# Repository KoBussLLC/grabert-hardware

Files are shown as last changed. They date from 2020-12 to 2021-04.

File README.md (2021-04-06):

# Grabert Keyboard Hardware

💻 🖥️ ⌨️ Open-source ~60% Mechanical Keyboard 🎉

Build Guide and additional information [here](doc/BUILDGUIDE.md)!

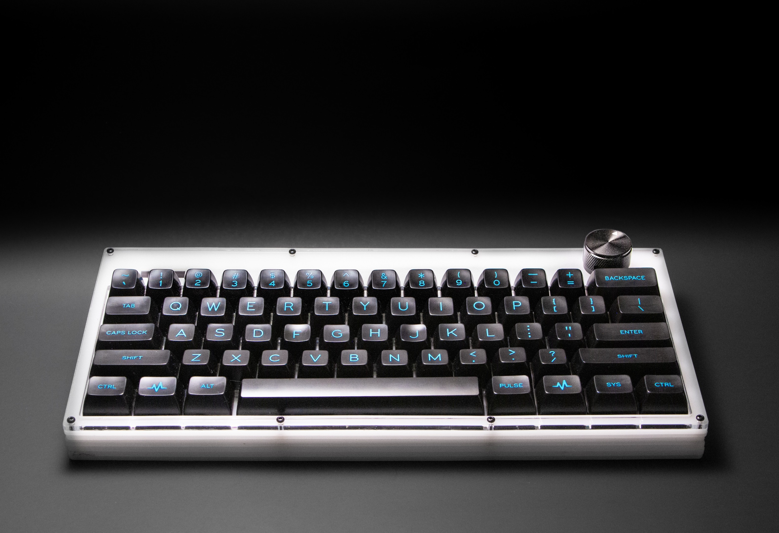
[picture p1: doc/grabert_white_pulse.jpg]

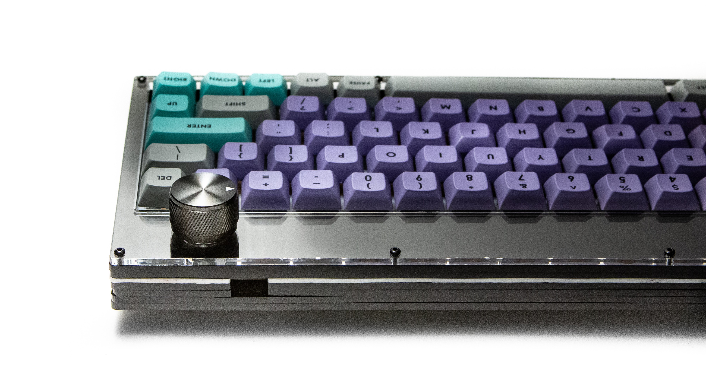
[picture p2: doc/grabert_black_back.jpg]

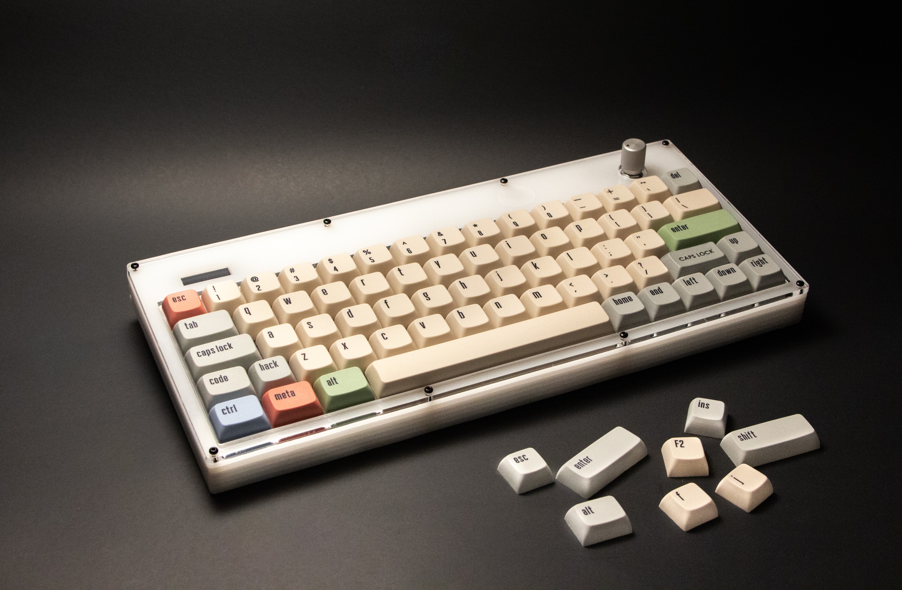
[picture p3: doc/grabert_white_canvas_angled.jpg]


<details>
  <summary>Screen and Foot</summary>
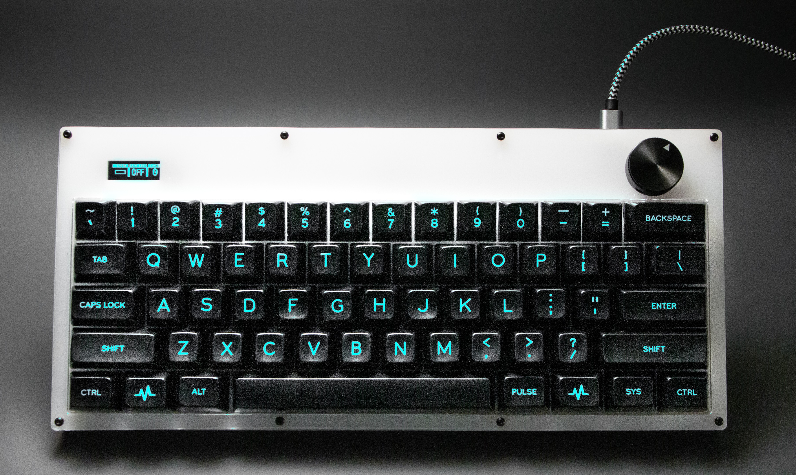
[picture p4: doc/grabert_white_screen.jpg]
  
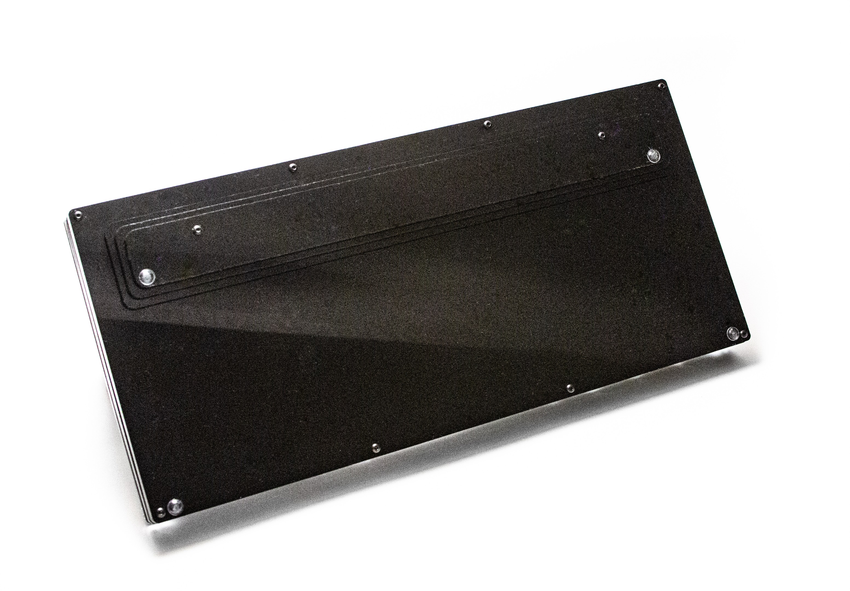
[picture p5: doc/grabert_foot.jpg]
  
</details>
<br/>
<details>
  <summary>PCB Images</summary>
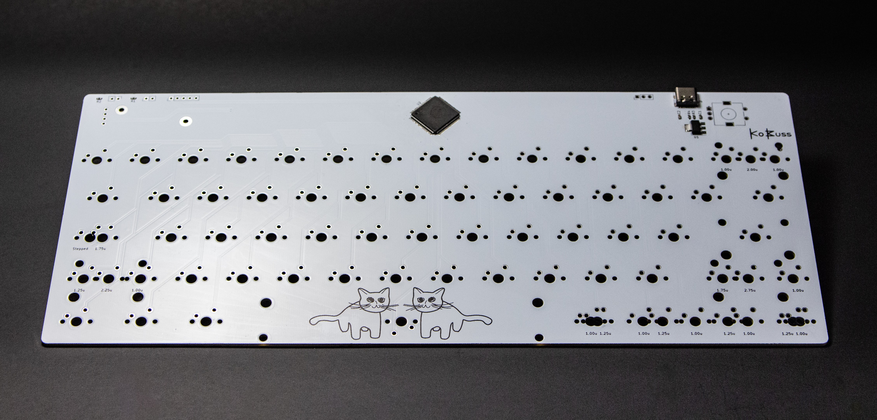
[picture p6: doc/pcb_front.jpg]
  
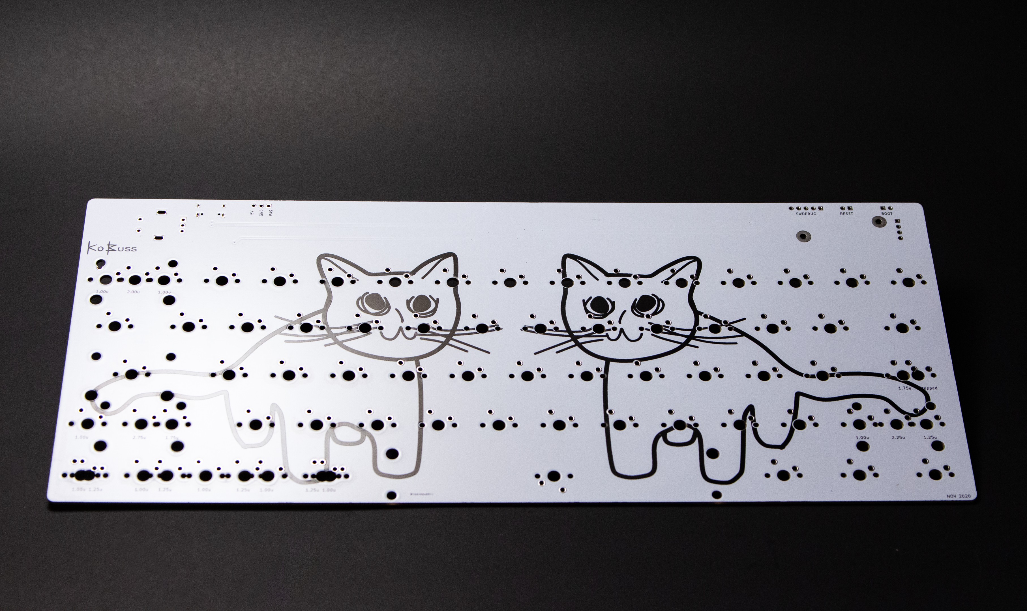
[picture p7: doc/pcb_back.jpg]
  
</details>
<br/>

[PCB design video](https://youtu.be/ezk02GJ9iMs)

[Case design video](https://youtu.be/DsW-hKeB3mc)

## Features

- OLED Screen
- Rotary Knob
- Sandwich Mount Case
- POM Switch Plate
- [4 Layout Options](doc/BUILDGUIDE.md#preparation-and-layout-decision)
- 32-bit Microcontroller

### Powered by

- [QMK](https://github.com/qmk/qmk_firmware) ([KoBuss QMK Fork](https://github.com/KoBussLLC/qmk_firmware))
- [VIA](https://caniusevia.com/)

## PCB

This project uses KiCad 6 for electrical CAD

### Electrical Design Constraints
- No diode matrix enabled by LQFP 100 MCU Footprint
- 32-bit STM32 Microcontroller (STM32F072V8T6)
- USB-C
- PCB Mount Switches
- PCB Mount Stabilizers
- Push-Button Encoder
- 0.91" 128x32px I2C OLED Display (SSD1306)

### Changes
- V0 had incorrectly valued bypass capacitors. Testing showed no obvious issues, but it is not preferable.

## CAD

This project uses FreeCAD 0.19 for mechanical CAD

### Required Add-ons
- Assembly 4
- Fasteners
- kicadStepUpMod

### Mechanical Design Contraints
- ~60% Keyboard Layout
- 5 Layout Options
- Push Button Encoder
- OLED 128x32 Screen
- Fully Laser Cut Case
- POM Switch Plate
- 2mm diameter fasteners

### Acrylic Sheet Stackup

Main Case Stackup. "0" is the bottom of the case.

| Sheet Number | FreeCAD "Part" | Thickness | Material | Shape |
| - | - | - | - | - |
| 0 | bottom | 0.125 in | Acrylic |  |
| 1 | closed_spacer | 0.125 in | Acrylic |  |
| 2 | usb_spacer | 0.125 in | Acrylic |  *with feet |
| 3 | usb_spacer | 0.125 in | Acrylic |  *with feet |
| 4 | switch_plate | 0.0625 in | POM/Acetal |  |
| 5 | closed_spacer | 0.125 in | Acrylic |  |
| 6 | colored_top | 0.125 in | Acrylic |  |
| 7 | clear_top | 0.125 in | Acrylic |  |

#### Angled Foot Stackup

Foot stackup. "0" is closest to the case and is on the "top"

| Sheet Number | FreeCAD "Part" | Thickness | Material |
| - | - | - | - |
| 0 | foot_0 | 0.125 in | Acrylic |
| 1 | foot_1 | 0.125 in | Acrylic |
| 2 | foot_2 | 0.125 in | Acrylic |

## License
MIT License

Copyright (c) 2021 KoBuss LLC

Permission is hereby granted, free of charge, to any person obtaining a copy of this hardware, software, and associated documentation files (the "Product"), to deal in the Product without restriction, including without limitation the rights to use, copy, modify, merge, publish, distribute, sublicense, and/or sell copies of the Product, and to permit persons to whom the Product is furnished to do so, subject to the following conditions:

The above copyright notice and this permission notice shall be included in all copies or substantial portions of the Product.

THE PRODUCT IS PROVIDED "AS IS", WITHOUT WARRANTY OF ANY KIND, EXPRESS OR IMPLIED, INCLUDING BUT NOT LIMITED TO THE WARRANTIES OF MERCHANTABILITY, FITNESS FOR A PARTICULAR PURPOSE AND NONINFRINGEMENT. IN NO EVENT SHALL THE AUTHORS OR COPYRIGHT HOLDERS BE LIABLE FOR ANY CLAIM, DAMAGES OR OTHER LIABILITY, WHETHER IN AN ACTION OF CONTRACT, TORT OR OTHERWISE, ARISING FROM, OUT OF OR IN CONNECTION WITH THE PRODUCT OR THE USE OR OTHER DEALINGS IN THE PRODUCT.

### For the Keyboard Community
You can produce and sell this keyboard. KoBuss LLC is not liable. Creator attribution is preferred but not required.

### License Change?
We initially licensed this under the Creative Commons Attribution-NonCommercial 4.0 International License, but have since decided to change it to MIT.
This would not be appropriate if the product was in production and had been forked/derived, but because we made the license change early on we deemed it acceptable.
If you have any issues with this change, please contact us directly.

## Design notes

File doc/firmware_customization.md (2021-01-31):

# Firmware Customization

## QMK Firmware

The keyboard firmware shipped with all Grabert keyboard is QMK with VIA enabled. To see the latest firmware, see the [KoBuss QMK Fork](https://github.com/KoBussLLC/qmk_firmware). It is reccomended to use VIA for keyboard configuration before diving into firmware customization, but it is only natural to see what mischief you can accomplish with your own 1's and 0's 💾.

The current firmware uses the OLED screen for WPM speed, caps lock indicator, and layer indicator. The images are hard coded using the `grabert.h` file and the [image2cpp](https://javl.github.io/image2cpp/) website is used to convert pixels into vertically packed bits. If you want to change what gets displayed, remove all the OLED logic and implement your own, or simply use image2cpp in the vertical mode to create the arrays your code needs 🎨.

By default the bottom-right modifiers and right shift are toggle-tap keys that are arrow keys on "tap" and modifiers on "hold", but you can use other advanced features by changing the keymap and possibly the config and make file.

### DFU and Reset

The STM32F072 series has an internal USB bootloader that is booted into from a software reset or by a hardware reset. It is much easier to use the software reset. To use the software reset, get into layer 2 with right and left modifiers and press the rotary encoder. If you change the keymap so that you can not trigger a software reset, you must take the case apart and trigger the reset in hardware. The boot pin must be pulled high while the MCU is reset. To do this on the Grabert PCB, simply use a wire and connect the boot jumper and while the boot jumper is connected, connect the reset jumper and the release the jumper. See the image in the *Debugger Programming* section for reference.

You should see a STMicroelectronics device show up your device tree, which means that your PCB is ready to be programmed.  `STMicroelectronics STM Device in DFU Mode`

To program your new firmware, flash a compiled bin with `dfu-util`. The STM32F072V8 only containes 64 Kbytes of flash, so make sure to not go crazy with too many stored images for the OLED. To learn more about building the firmware see the QMK docs.

Build Command
``` sh
make kobuss/grabert:via
```

Build and Flash Command
``` sh
make kobuss/grabert:via:dfu-util
```
### Debugger Programming

**This is not normally needed unless you need breakpoints or register level access**

To fully debug your firmware, you will need a JTAG or ST-Link programming device. Connect it to the SWD pins on the PCB and start a debug sesion!

To access the SWD pins, you must take the case apart:
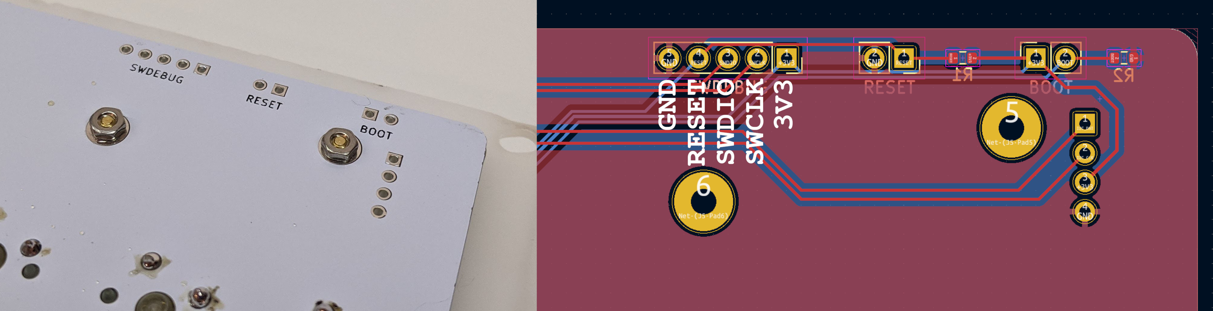
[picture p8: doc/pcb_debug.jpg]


### Extending Functionality

#### LED Underlighting
Pin A9 of the STM32072 is broken out on the left of the USB, along with the USB 5V rail and ground. Pin A9 is a TIM1_CH2 enabled pin and therefore could be used for dimmable single color underglow or bit banged for an RGB string. This is not officially supported but may be documented further in the future.

This pin could also be used as an input in a case where you want a giant mechanical switch for some special function.

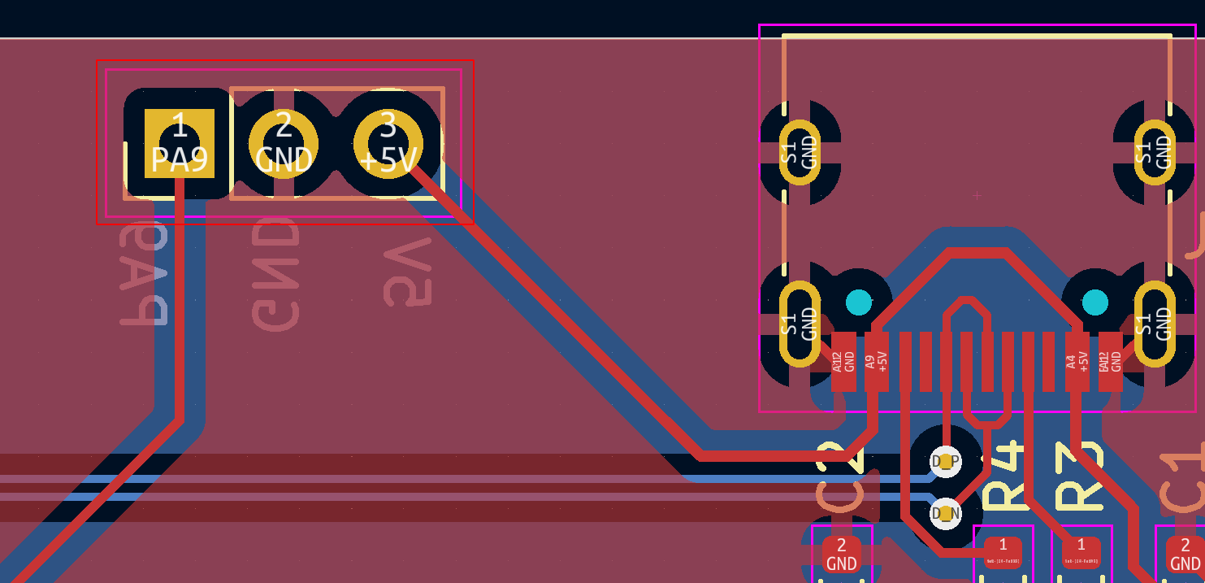
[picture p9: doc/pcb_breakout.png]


### Wanted QMK additions to Grabert
If you are working on the firmware for Grabert and want to see what you might be able to add, the following is a list of things that we believe others could benefit from.

- Implement STM32 RTC to enable programable clock to display on the OLED
- Add configurable WS2812 or PWM based LED on PA9
- Crazy cool OLED implementations!
- Add custom VIA "eeprom" storage for encoder along with custom VIA implementation of the encoder

## Rust Firmware

TODO: Fork an existing Rust keyboard firmware and write a Grabert implementation

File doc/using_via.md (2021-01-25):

# Using VIA

QMK firmware with VIA enabled is the default firmware on all Grabert keyboards. VIA allows for dynamic changing of keymaps through a desktop application. VIA does not currently support all of the advanced [software features of QMK](https://docs.qmk.fm/#/feature_auto_shift), so if you are interested in using those, see the [firmware customization documentation](firmware_customization.md).

For all official VIA documentation see the VIA [website](https://caniusevia.com/) and QMK's  [repository]().

## Setting up VIA for Grabert

1. Download VIA from the [official website](https://caniusevia.com/) for your respective OS.

2. As of right now, Grabert is not in the upstream VIA keyboards repo, therefore you also need to download the [grabert.json](https://raw.githubusercontent.com/KoBussLLC/keyboards/kobuss/src/kobuss/grabert/grabert.json) from the KoBussLLC fork. (Click the hyperlink and right-click "Save Page As..." into your computer)
   
3. Launch VIA through your OS
4. Select "Import Keymap" from your OS's menu
5. Select the `grabert.json` file from your computer that you just downloaded
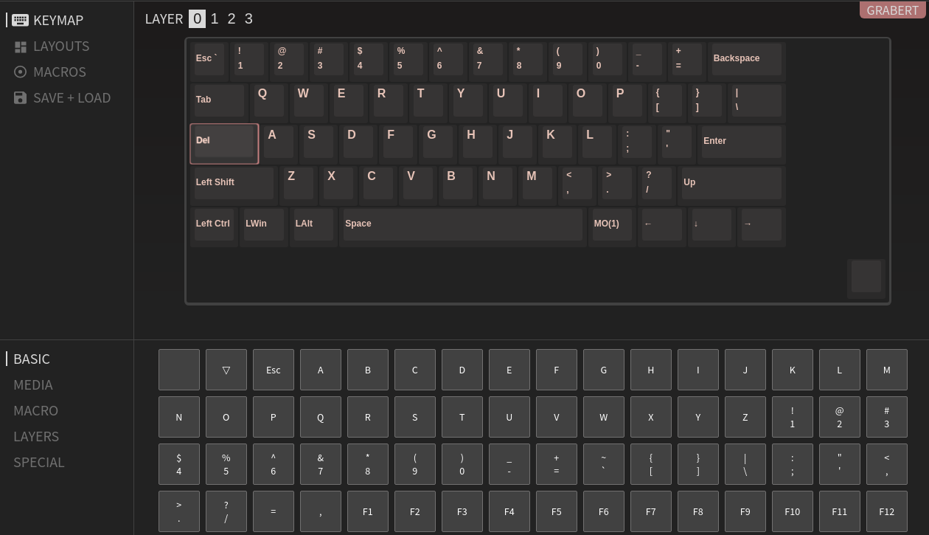
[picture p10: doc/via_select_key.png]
6. Use VIA in whatever way you want. The main operations are selecting a layer and then a key and choosing what you want the coresponding key to represent. Note that the mapping changes immediately after selecting a new key for the highlighted switch. 
7. Dive into setting up custom "Macros" and advanced layering once you are ready.

### Additional Information

- [Keyboard Layout Editor Permalink](http://www.keyboard-layout-editor.com/##@@_x:3%3B&=0,0&=0,1&=0,2&=0,3&=0,4&=0,5&=0,6&=0,7&=0,8&=0,9&=0,10&=0,11&=0,12&_w:2%3B&=0,13%0A%0A%0A0,0&_x:0.5%3B&=0,13%0A%0A%0A0,1&=0,14%0A%0A%0A0,1%3B&@_x:3&w:1.5%3B&=1,0&=1,1&=1,2&=1,3&=1,4&=1,5&=1,6&=1,7&=1,8&=1,9&=1,10&=1,11&=1,12&_w:1.5%3B&=1,13%3B&@_x:3&w:1.75%3B&=2,0&=2,1&=2,2&=2,3&=2,4&=2,5&=2,6&=2,7&=2,8&=2,9&=2,10&=2,11&_w:2.25%3B&=2,12%3B&@_w:1.25%3B&=3,0%0A%0A%0A1,1&=3,1%0A%0A%0A1,1&_x:0.75&w:2.25%3B&=3,0%0A%0A%0A1,0&=3,2&=3,3&=3,4&=3,5&=3,6&=3,7&=3,8&=3,9&=3,10&=3,11&_w:2.75%3B&=3,12%0A%0A%0A2,0&_x:0.5&w:1.75%3B&=3,12%0A%0A%0A2,1&=3,13%0A%0A%0A2,1%3B&@_x:3&c=%23AAAAAA&w:1.25%3B&=4,0&_w:1.25%3B&=4,1&_w:1.25%3B&=4,2&_c=%23cccccc&w:6.25%3B&=4,3&_c=%23AAAAAA&w:1.25%3B&=4,4%0A%0A%0A3,0&_w:1.25%3B&=4,5%0A%0A%0A3,0&_w:1.25%3B&=4,7%0A%0A%0A3,0&_w:1.25%3B&=4,8%0A%0A%0A3,0%3B&@_y:0.25&x:13%3B&=4,4%0A%0A%0A3,1&=4,5%0A%0A%0A3,1&=4,6%0A%0A%0A3,1&=4,7%0A%0A%0A3,1&=4,8%0A%0A%0A3,1&_x:1.5&c=%23cccccc%3B&=4,9) used to generate the VIA grabert.json file
- [VIA Layout documentation](https://caniusevia.com/docs/layouts)

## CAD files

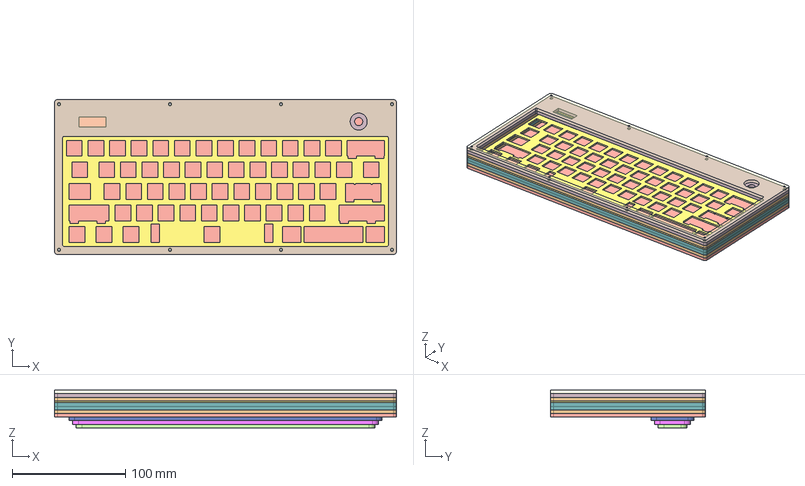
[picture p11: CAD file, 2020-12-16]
CAD/grabert.FCStd
301.6 x 136.5 x 33.3 mm

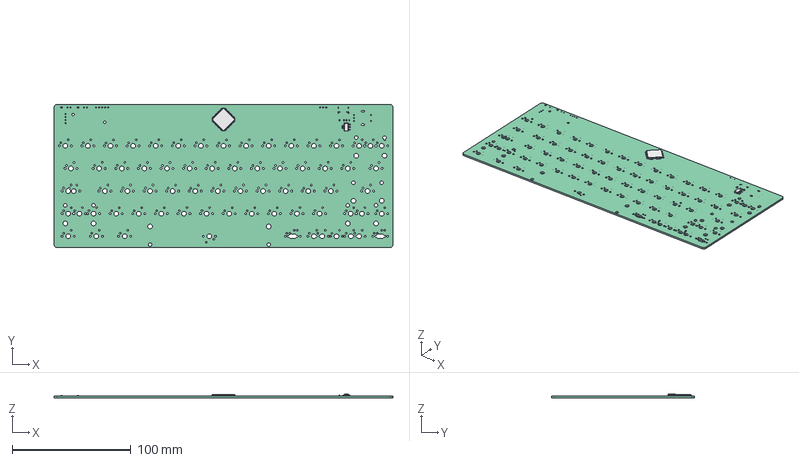
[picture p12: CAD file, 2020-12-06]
CAD/grabert_pcb.FCStd
285.8 x 120.7 x 3.30 mm
Pcb_4306
"C1"_C_0603_1608Metric_5db69710-2d0d-45d7-a742-beb49e07931f x 2
"U2"_LQFP_100_14x14mm_P05mm_719b990f-ae4c-490b-9cd7-5392cd54d5f2
"R2"_R_0603_1608Metric_b3f198d9-8440-4a91-92b4-b595c153e976 x 4
"U1"_SOT_223_c46af92f-9185-4327-9a7a-dfaa81b7fe2d

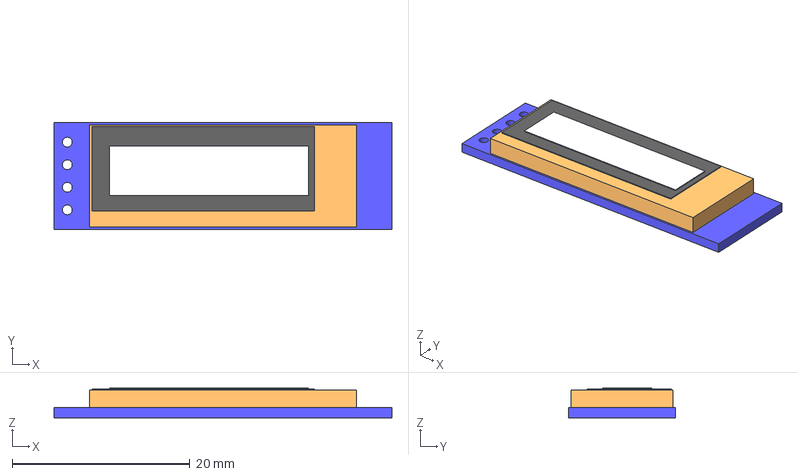
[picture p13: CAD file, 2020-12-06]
CAD/ssd1306oled128x32.FCStd
38.0 x 12.0 x 3.35 mm
Glass
PCB
BlackFilm
Pixel Area

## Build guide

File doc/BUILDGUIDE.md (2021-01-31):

# Grabert Build Guide
- [Grabert Build Guide](#grabert-build-guide)
  - [Preparation and Layout Decisions](#preparation-and-layout-decisions)
    - [Determining Your Layout](#determining-your-layout)
    - [Required Components that are not supplied](#required-components-that-are-not-supplied)
    - [Required Tools](#required-tools)
  - [Build Instructions](#build-instructions)
    - [PCB Testing and Setup](#pcb-testing-and-setup)
    - [Switch Plate Assembly](#switch-plate-assembly)
    - [Case Assembly](#case-assembly)
  - [Errata](#errata)
## Preparation and Layout Decisions
### Determining Your Layout
The first step in building your keyboard is deciding what layout you want to use. If you have already picked out a keycap set, make
sure that the layout you choose can be achieved with the keycaps that you have.
With a standard 60% layout, Grabert uses 61 PCB Mount MX style switches with 1x 6.25U and 4x 2.00U PCB mount stabilizers. Grabert can be built with both PCB mount and plate mount MX switches, while the PCB mount switches provide better alignment but more difficult installation, and the plate mount switches are the inverse.  Grabert offers 4 layout options that can change these component requirements, as shown in the table below. With that said, it is recommended to have at least 3 extra switches on hand in case you have a wild child spring or you just have a mysterious defunct switch.

| Option | Key Size Change | Switch Requirement Change | Stabilizer Requirement Change |
|-|-|-|-|
| Split Backspace | 2.0U ⇨ 1.0U + 1.0U  | +1 | -1x 2.00U |
| Split Left Shift | 2.25U ⇨ 1.25U + 1.0U | +1 | -1x 2.00U |
| Split Right Shift | 2.75U ⇨ 1.75U + 1.0U | +1 | -1x 2.00U |
| Five Right Modifiers | 5x 1.25U ⇨ 4x 1.0U | +1 | No Change |

If this is your first time building a keyboard, it may be nice to use a default 60% layout, as you will still be able to use the right modifiers (bottom-right hand corner) as tapped arrow keys and any keycap set supports this layout. Use KLE's preset as an [example](http://www.keyboard-layout-editor.com/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'&_w:2.25%3B&=Enter%3B&@_w:2.25%3B&=Shift&=Z&=X&=C&=V&=B&=N&=M&=%3C%0A,&=%3E%0A.&=%3F%0A%2F%2F&_w:2.75%3B&=Shift%3B&@_w:1.25%3B&=Ctrl&_w:1.25%3B&=Win&_w:1.25%3B&=Alt&_a:7&w:6.25%3B&=&_a:4&w:1.25%3B&=Alt&_w:1.25%3B&=Win&_w:1.25%3B&=Menu&_w:1.25%3B&=Ctrl). Grabert supports a "1.25U" stem stepped caps lock key.

Grabert default layout:

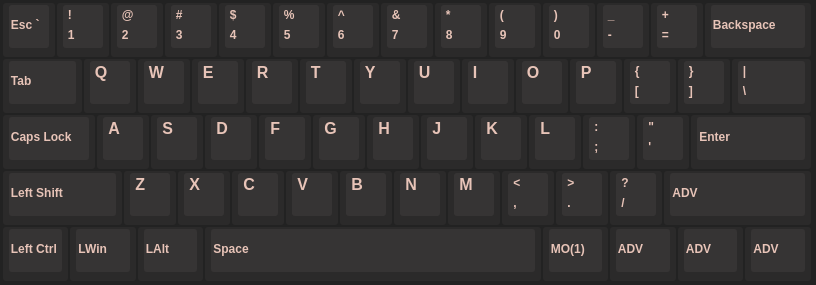
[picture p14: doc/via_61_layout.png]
Grabert 61 key layout


Grabert with all layout options utilized:

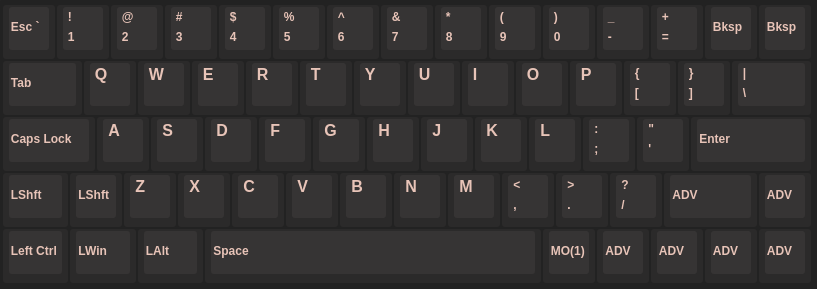
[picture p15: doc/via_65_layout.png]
Grabert 65 key layout


Once you have your layout chosen, grab your favorite switches and get them lubed!

We use [Super Lube 51004](https://www.amazon.com/gp/product/B000UKUHXK/) for our switches and [Super Lubes 21030](https://www.amazon.com/gp/product/B06WLQ251B/) for our stabilizers, but use whatever you like. We loosely follow [Taeha Types's Switch Lubing Guide](https://youtu.be/qSgPKPoFo2k) and [Taeha Types's Clipping, Lubing, and Band-aiding Guide](https://youtu.be/cD5Zj-ZgMLA) as a process for lubing our personal switches and stabilizers.

### Required Components that are not supplied

- Keycaps (Options: [Amazon](https://www.amazon.com/gp/product/B081DDG7CJ/), [MK](https://mechanicalkeyboards.com/shop/index.php?l=product_list&c=429&show=100&sortby=num_sold:desc))
- PCB Mount MX Style Switches (See [above](#determining-your-layout) for quantity) (Option: [Amazon](https://www.amazon.com/gp/product/B07TYD6Z3R/))
- PCB Mount Stabilizers (See [above](#determining-your-layout) for size/quantity) (Option: [Amazon](https://www.amazon.com/gp/product/B07ZLXCWY9/))
- Switch/Stabilizer Lubricant (**Optional**)
- USB-C Cable (Option: [Amazon](https://www.amazon.com/gp/product/B07VQYLXJC/))

### Required Tools

| Tool | Purpose |
|-|-|
| Soldering Iron and Solder | Soldering in MX style switches |
| Metric Hex Keys (1.5mm & 2mm) | Assembling the case |
| Small Phillips Head ScrewDriver| Screwing in PCB Mount Stabilizers |
| Pliers | Tightening hex nuts |
| Rubber Band | Holding the OLED Screen in place |
| Wire or Paperclip | Testing PCB Connections |

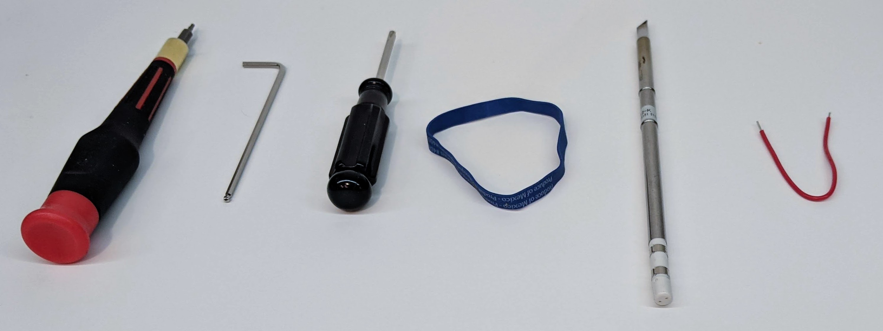
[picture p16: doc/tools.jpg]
Required Tools


## Build Instructions

The beginning of the build is the most difficult, so get your coffee or tea and get going! ☕🔨

### PCB Testing and Setup
1. Launch VIA and import the `grabert.json` keymap. If you do not know how to do this, see the [Using VIA guide](using_via.md).
2. Plug-in your Grabert PCB via the USB-C connector and make sure that VIA recognizes the keyboard. (Note: We test all PCBs are recognized before shipment, but this makes sure everything is working correctly when delivered.)
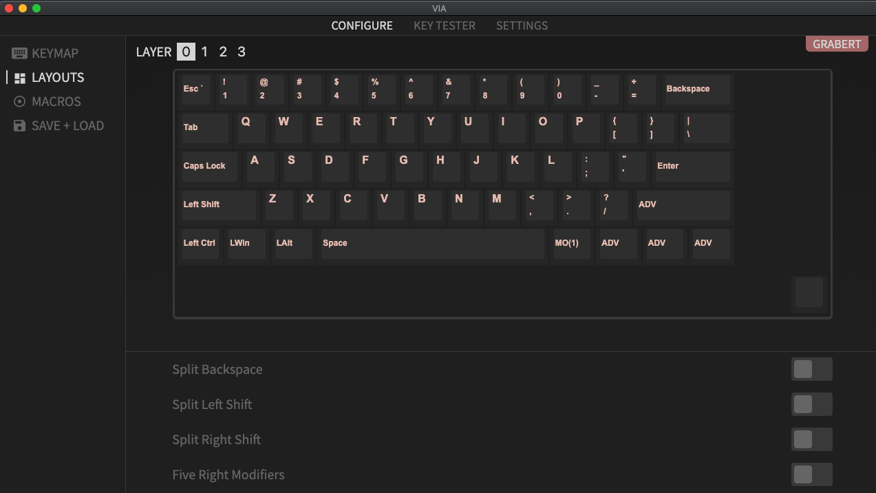
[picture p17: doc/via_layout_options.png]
3. Go to the "LAYOUTS" section and define which layout options you want. See the [Determining Your Layout](#determining-your-layout) section for help on determining what you should use. 
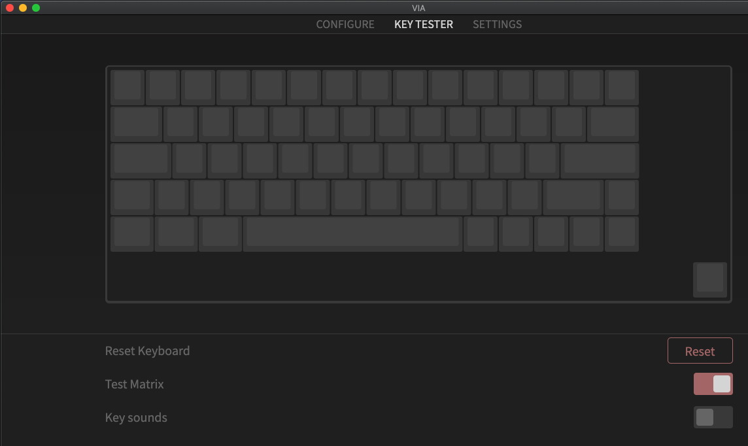
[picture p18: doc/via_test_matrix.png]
4. Go to the "KEY TESTER" panel in VIA and toggle the "Test Matrix" 
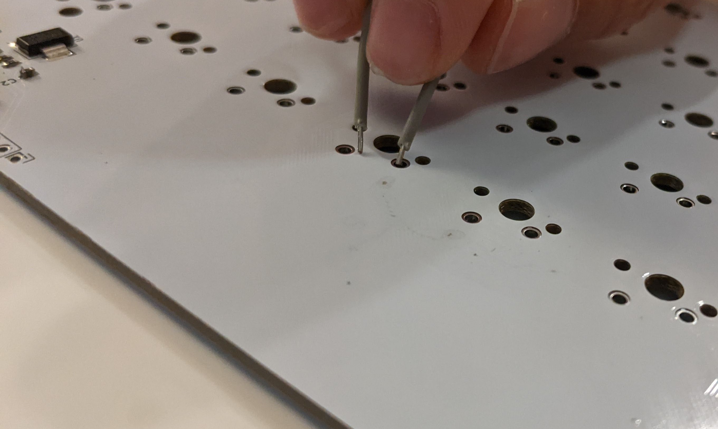
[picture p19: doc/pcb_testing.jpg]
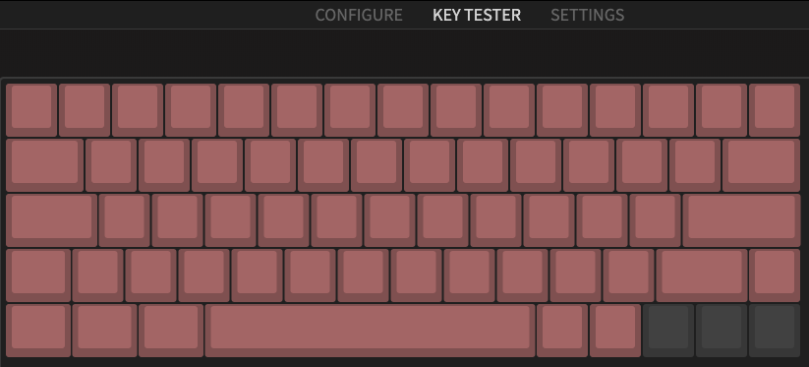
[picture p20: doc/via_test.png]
5. Use a spare wire or a paperclip to test that each key is registered. You do not need to light up the lone square at the bottom right corner, as this represents the encoder.  
6. Unplug the USB-C cable from the PCB once all keys are "lit" except for the bottom-right hand key. If not all keys light up, contact us at kobussllc@gmail.com
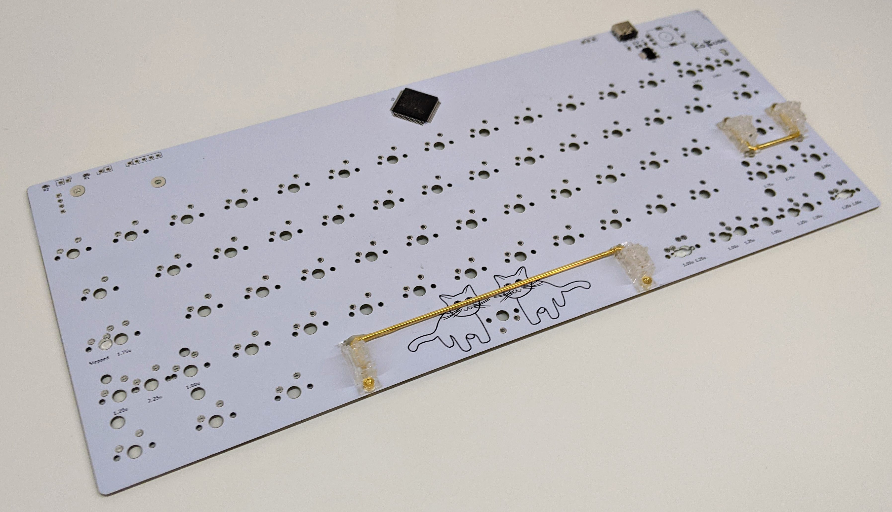
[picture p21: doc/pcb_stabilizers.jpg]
7. Lubricate your stabilizers if you wish, and then install them onto the PCB. To install the stabilizers, snap them onto the PCB and screw them in from the back of the PCB. The side of the stabilizer with the screw hole goes into the smaller hole in the PCB. The screw hole will be towards the top for all the small stabilizers and towards the bottom for the large space bar stabilizer (reference the picture). Screw them in slightly past hand tight. 

### Switch Plate Assembly

1. Gather the POM switchplate and your lubricated switches. Place **all** the switches that match your layout pattern that you have chosen into the switch plate. The metallic pins of the switches should be towards the top edge, except for the space bar. Feel free to reference the PCB, as the switch pins should fit into the holes.
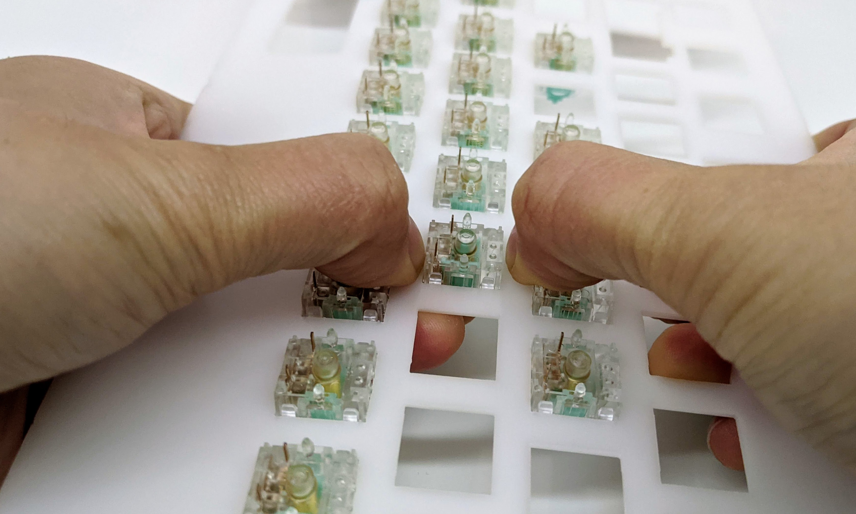
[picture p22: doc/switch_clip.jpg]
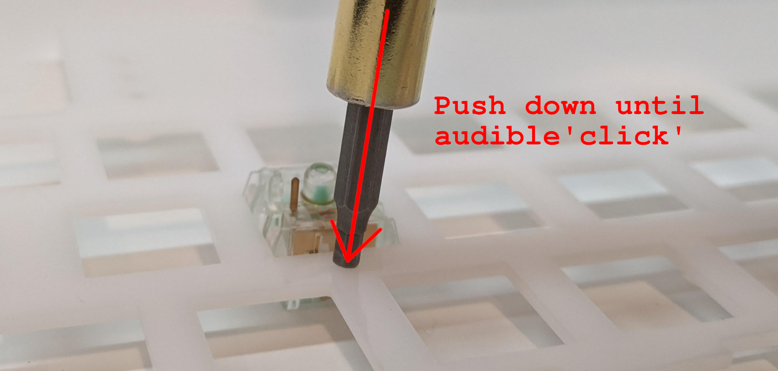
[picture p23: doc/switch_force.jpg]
To make sure that the switch is “clipped” in place and is securely in the switch plate, use your thumb and opposing finger to apply pressure at the clip in point and the switch plate. Make sure you hear a clicking sound (sometimes faint). This may be difficult on your hands, so you can use a blunt object like a screwdriver to apply direct pressure to the area of the switchplate next to the clip of the switch. (See [Errata](#errata) for why this is)  In spaces like the right modifier area, make sure you reference the PCB to make sure the switches are in the correct location of the cutout. Note: The switch should be perpendicular to the switchplate.  
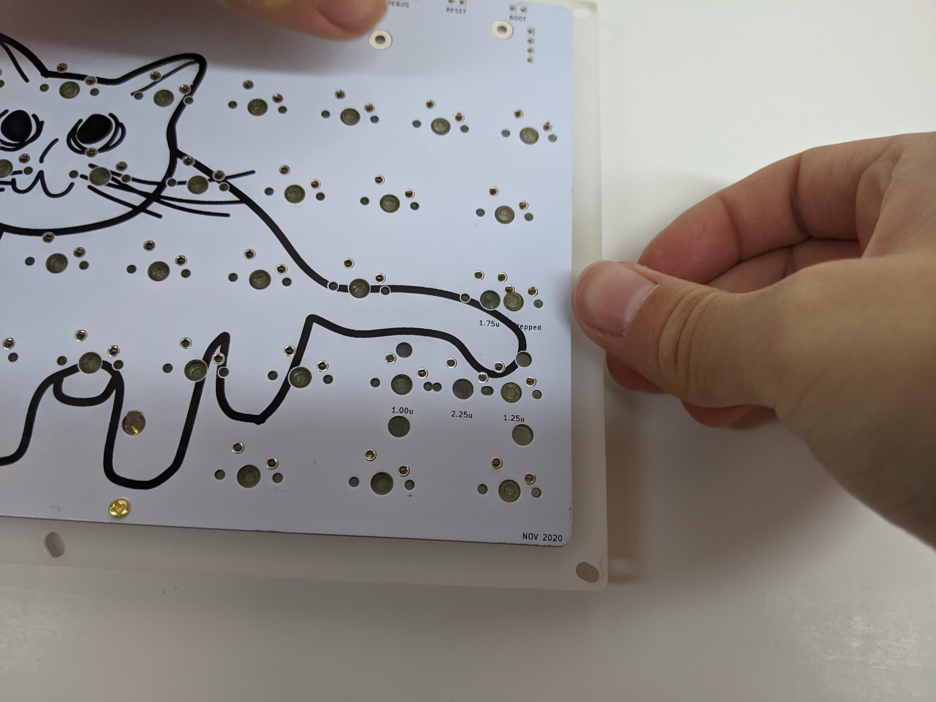
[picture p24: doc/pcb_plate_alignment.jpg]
2. With all of the switches in the switch-plate, place the switch plate onto the PCB. This step may seem simple, but it is important to do it without applying pressure that may push the switches out of the switch-plate or bend the pins. Make sure you can see all the pins aligned with the desired holes before applying any pressure.  You may also need to correct for any switch placement misalignment. 
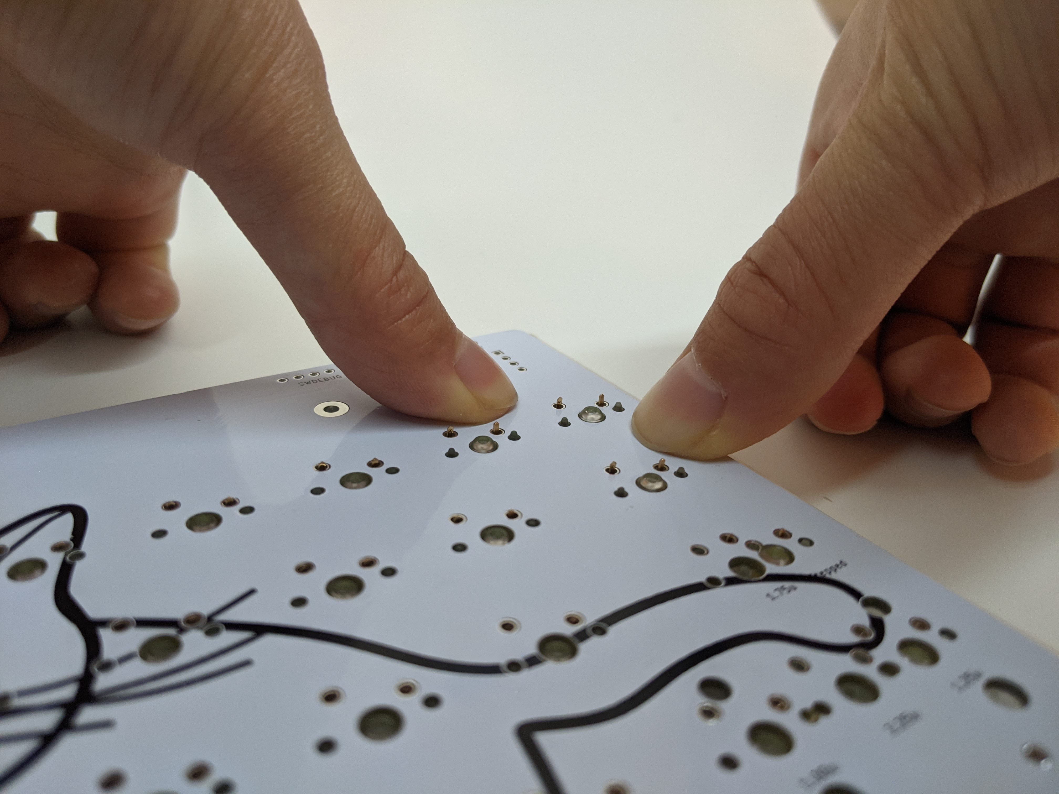
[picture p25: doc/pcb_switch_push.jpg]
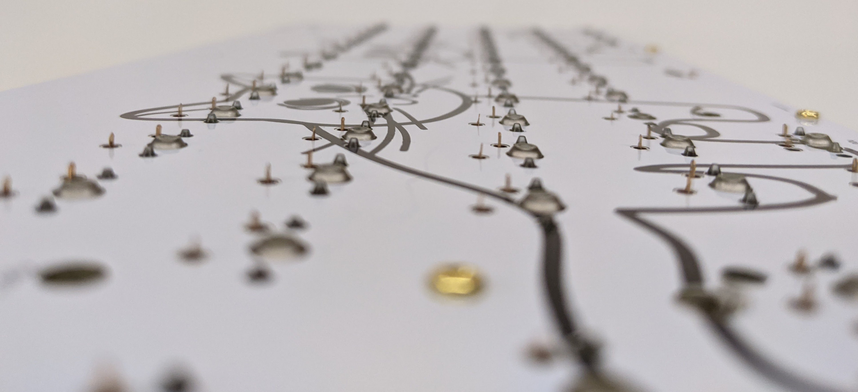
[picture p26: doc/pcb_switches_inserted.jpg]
3. Press down on the PCB, with the top of the switches touching your work surface. This may take quite a bit of pressure and is best done from one corner to another. Another method is to pick up the PCB and apply opposite pressure with single switches and the PCB. Make sure that all switches are pressed in all the way and perpendicular. Any misalignment here could cause your keycaps to touch each other.  
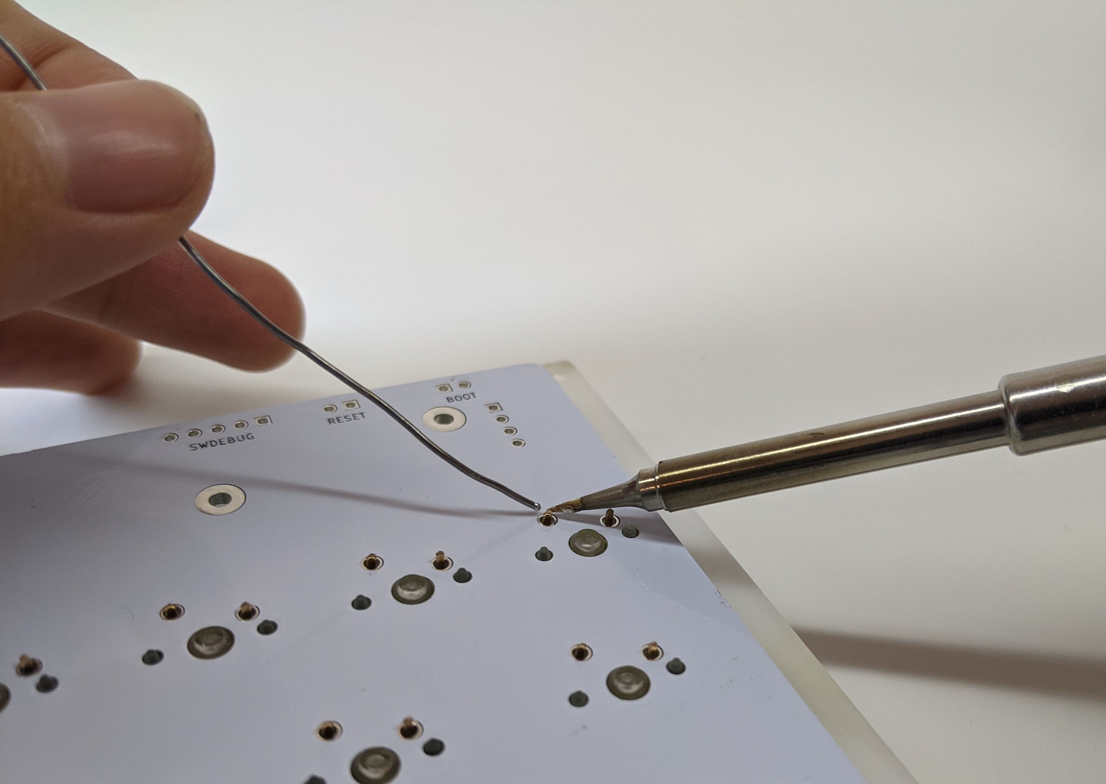
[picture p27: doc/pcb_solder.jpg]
4. With all the switches inserted into the PCB, with the switch plate sandwiched between, solder all pins of the switches. Note that the bottom pin is the ground pin and may take more heat from your soldering iron. [Sparkfun's Soldering Guide](https://learn.sparkfun.com/tutorials/how-to-solder-through-hole-soldering/all) for reference. 
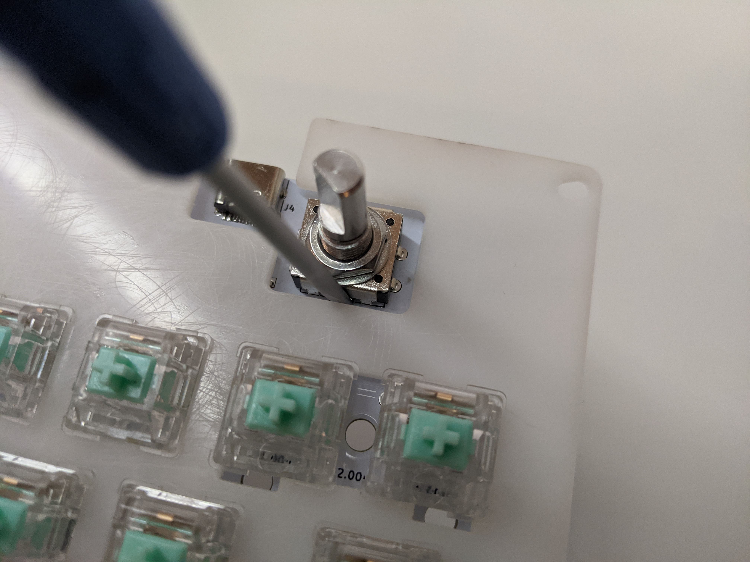
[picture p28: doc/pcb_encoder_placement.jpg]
5. After soldering all the switches, take the encoder and forcefully place the pins into the PCB's top-right corner. If it is feeling extra difficult, you may need to push on the tabs with a screwdriver to make the encoder snap into place. 
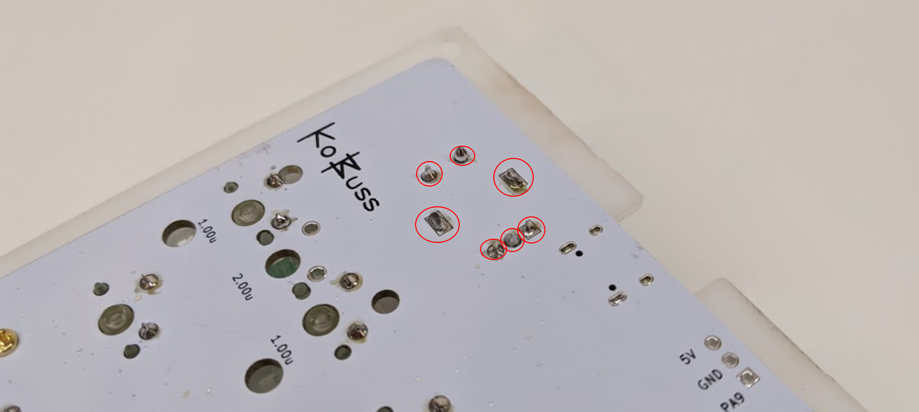
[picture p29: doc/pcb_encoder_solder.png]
6. Solder all 7 pins of the rotary encoder and make sure to take off the washer and nut on the top of the rotary encoder. 
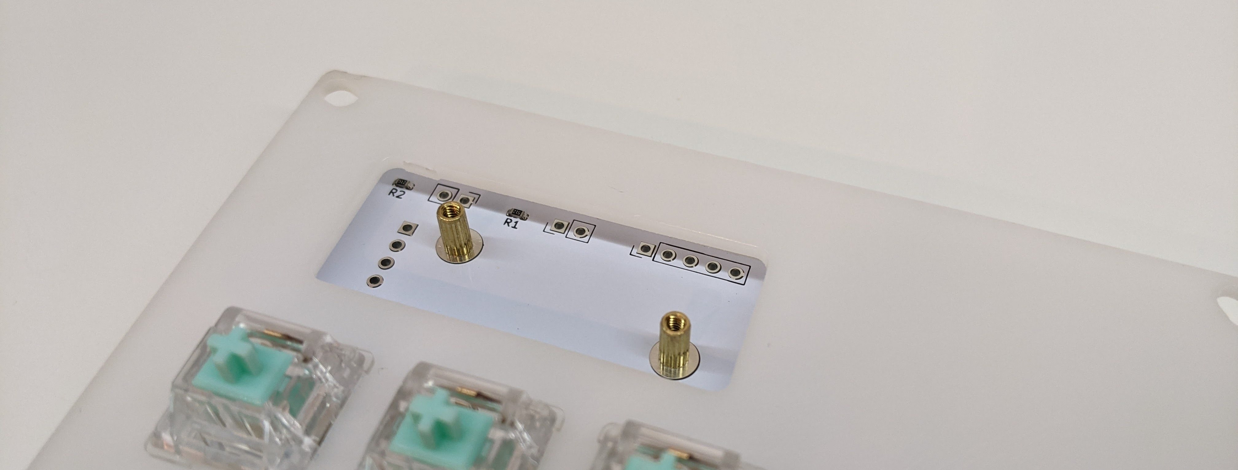
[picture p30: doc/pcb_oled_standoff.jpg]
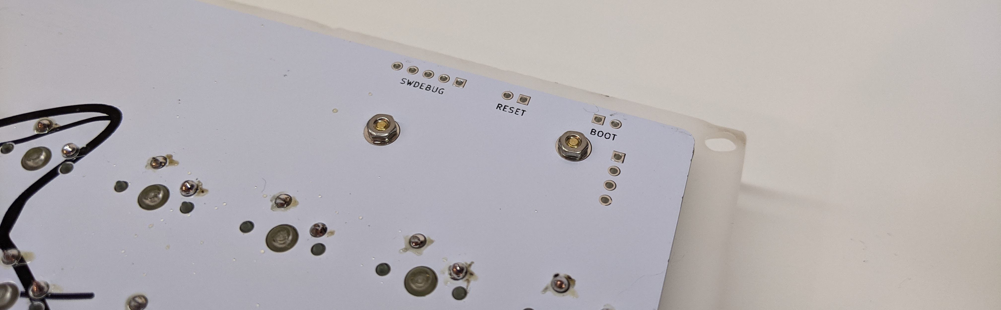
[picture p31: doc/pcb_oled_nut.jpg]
7. Take the two 6mm standoffs with 2mm nuts and fasten them in the holes on the PCB under the OLED. These standoffs will support the OLED installation for easy alignment. The nuts can be tightened with pliers just past hand tight.  
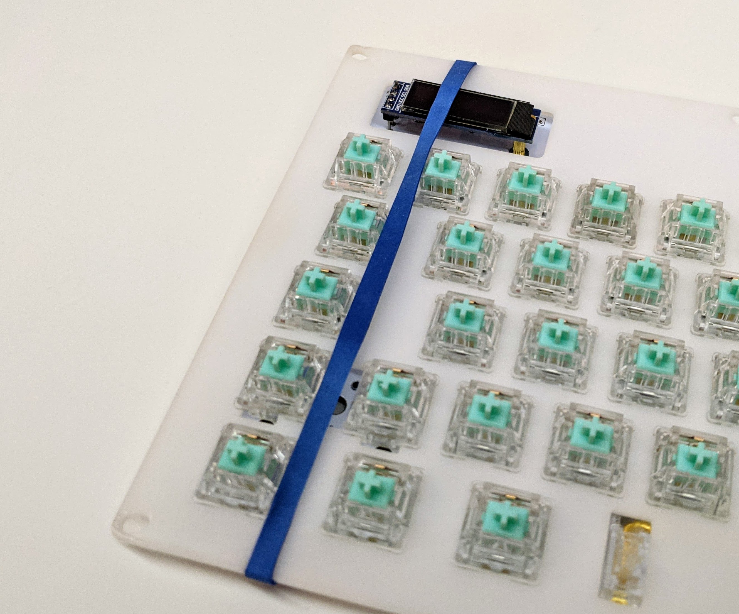
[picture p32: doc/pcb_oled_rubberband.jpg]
8. Insert the OLED display (peel the protective sheet off) into the top and rest it upon the installed standoffs. Recommended: Stretch a rubber band around the assembly to hold the OLED in place while you solder it. If you cannot get your OLED to be aligned both horizontally and vertically you may need to **gently** bend the pins that are connected to the OLED PCB. 
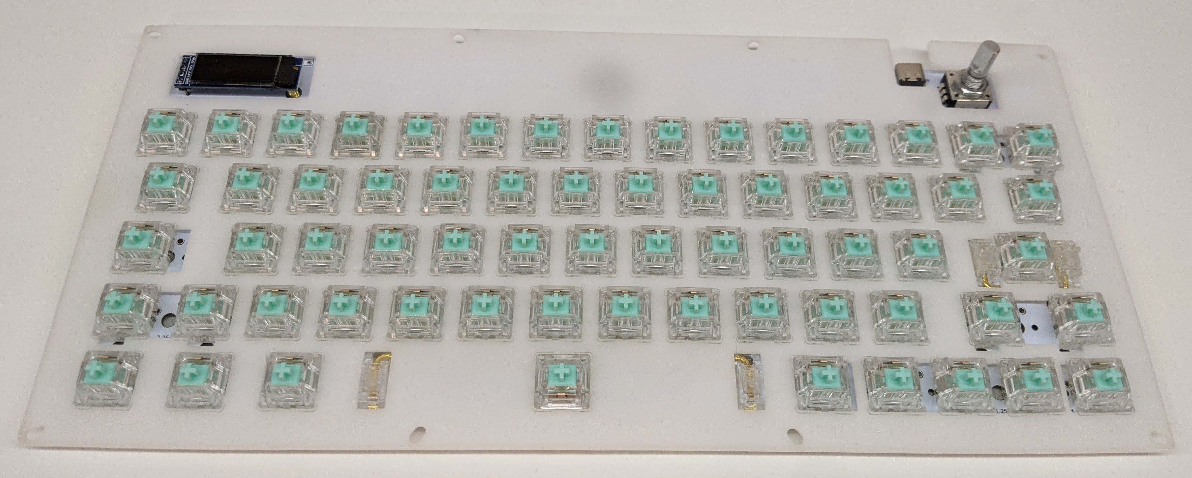
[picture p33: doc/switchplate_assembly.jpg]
9. Solder the four pins of the OLED display and make sure the display is aligned. It is alway good to solder just one pin and check alignment before soldering the rest of the pins. Note that the ground (bottom) pin may take some extra soldering heat. 
10. Plug the switch plate assembly into the your computer via the USB-C connector
11. Go back to the "KEY TESTER" in VIA and reset the keyboard. Press all the switches to test and see if your soldering was successful. If some of the switches don’t work, check your solder connections and pins. If the OLED does not work, check its connections as well.
12. Unplug your partially assembled keyboard, we are in the home stretch! 🏁🏃

### Case Assembly

1. Clean the OLED display and solder joints with a cloth coated in isopropyl alcohol. **Do not clean the acrylic case with isopropyl alcohol as it will cause the acrylic to crack!**
2. Grab the casing materials and start with the bottom plate along with two 6mm standoffs and four screws (Skip the standoffs and foot pieces if you do not want an inclined keyboard)
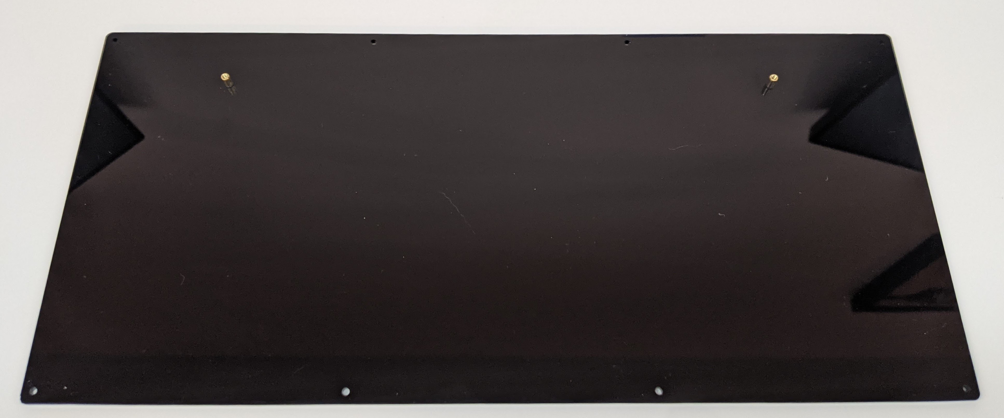
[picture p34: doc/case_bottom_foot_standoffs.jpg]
3. The bottom plate is symmetrical, so pick a side and call it "the top". Screw the two 6mm standoffs into the “center” holes with two screws. Hand tight is adequate. 
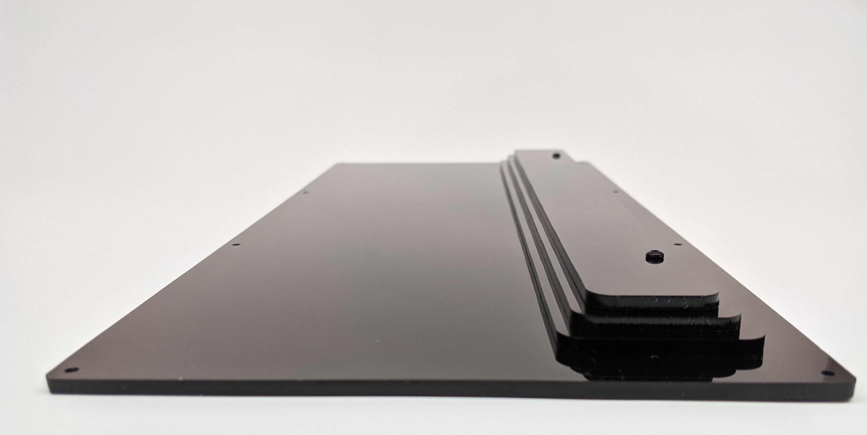
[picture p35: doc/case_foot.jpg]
4. Place the acrylic foot pieces from largest to smallest onto the standoffs. Capture the smallest acrylic piece by screwing in the remaining 2mm screws hand tight. The holes in the acrylic feet should be towards the top of the keyboard. 
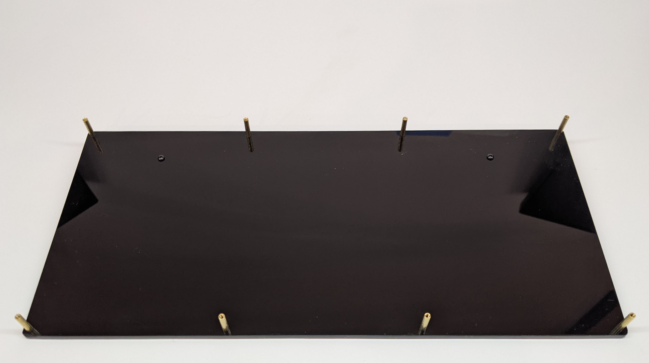
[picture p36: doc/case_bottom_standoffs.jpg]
5. Gather the rest of the standoffs (8) and 8 screws. Align a standoff with one of the holes on the top side of the base (opposite side of where the foot is) and screw in a screw to the standoff on the other side. Repeat 7 more times. 
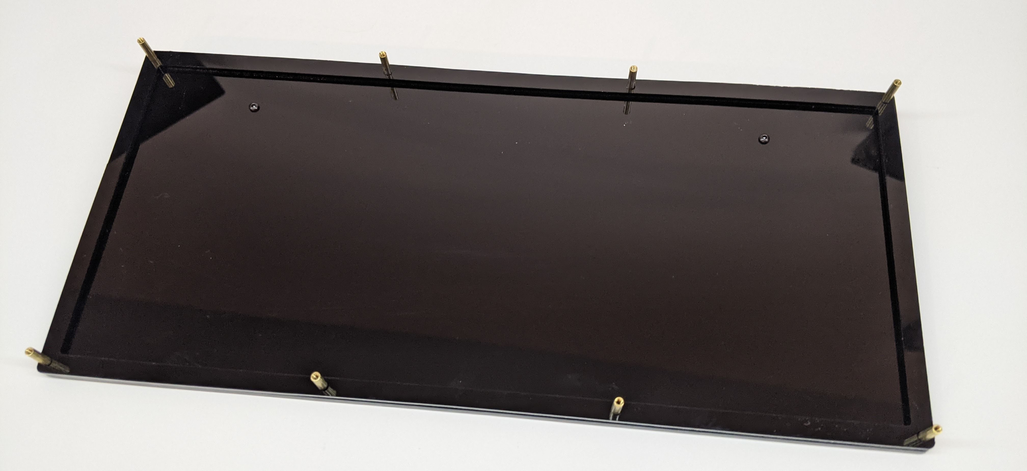
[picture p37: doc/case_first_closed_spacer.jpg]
6. Grab one closed spacer and press the spacer onto the base, aligning the holes of the spacer to the standoffs 
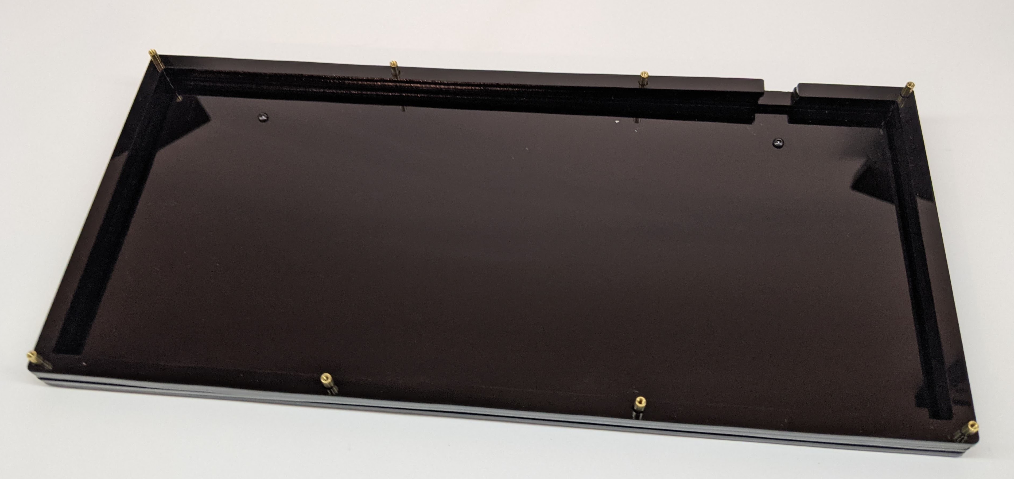
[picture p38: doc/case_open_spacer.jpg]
7. Place two open spacers on top, aligning the USB cut out to the right side. 
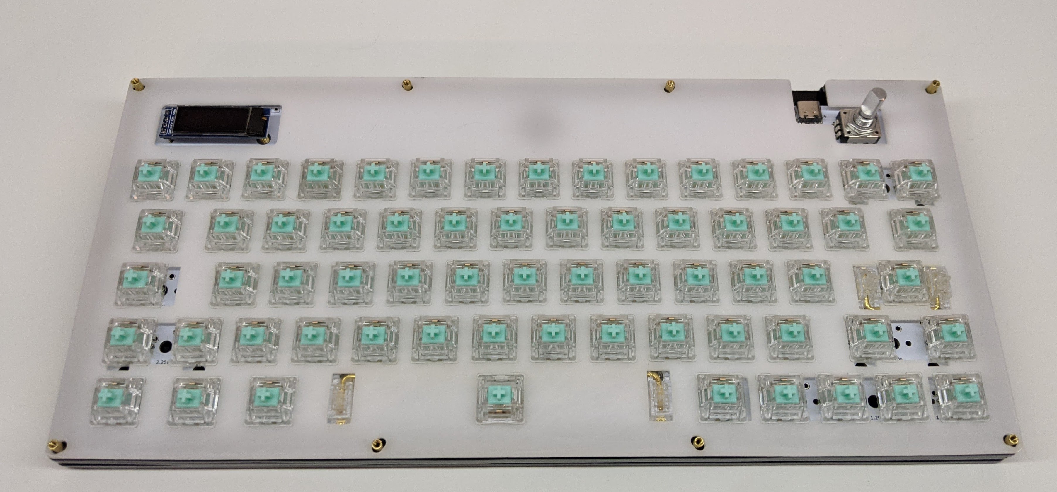
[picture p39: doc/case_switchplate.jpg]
8. Place your completed switch plate assembly on top.  
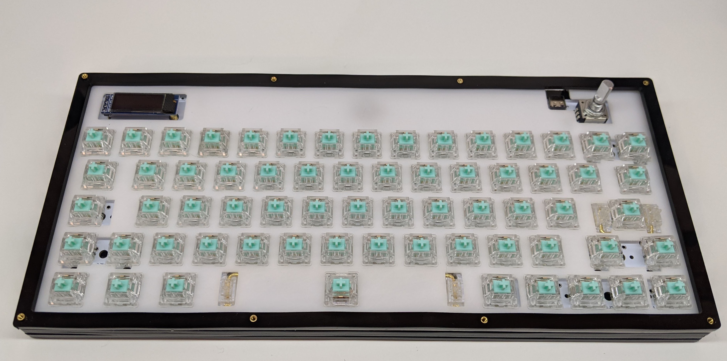
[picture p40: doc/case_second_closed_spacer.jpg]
9. Place the last closed spacer onto the switchplate. 
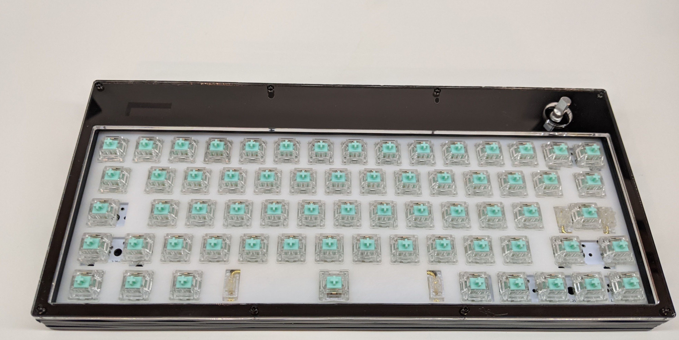
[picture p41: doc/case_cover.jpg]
10. Lastly, grab the opaque top with the opening for the OLED screen and align the holes with the standoffs. Clean the opaque top with wet cloth before placing the clear cover on top. Then, take the remaining screws and screw in the top. Note: If you are having difficulty threading in the top screws, make sure all the holes are aligned and loosen the bottom screws a couple of turns. 
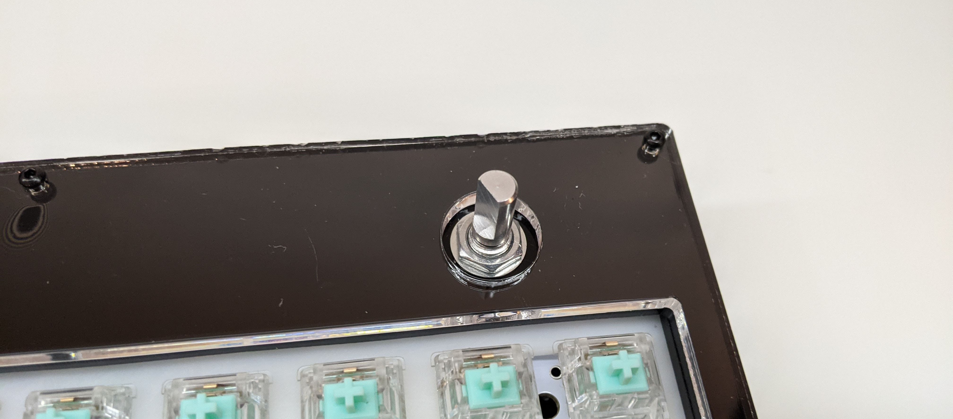
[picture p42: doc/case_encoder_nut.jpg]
11. Take the rotary encoder washer and nut and fasten them on top of the encoder. Use pliers to tighten the nut a 1/4 turn past touching the plate. Overtightening could cause your plate to bend preventing insertion of the USB cable. 
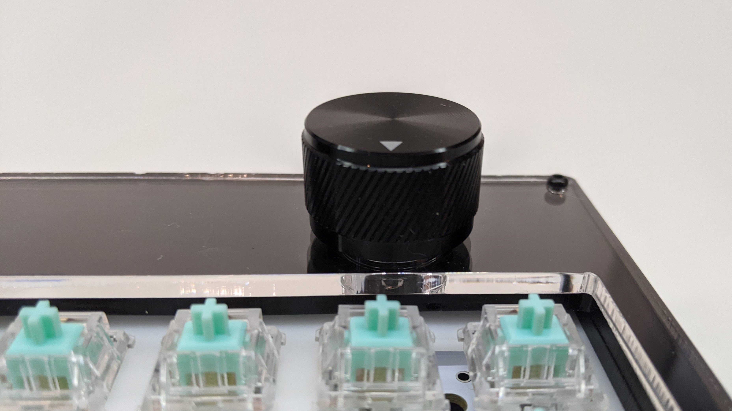
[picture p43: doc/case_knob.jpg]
12. Unscrew the rotary encoder knob set screw and then place it on the top of the rotary encoder. Tighten the set screw while holding the knob slightly away from bottoming out. This makes it so that when you press the knob you are not hitting the acrylic, but actuating the rotary encoder switch. 
13. Place the rubber feet onto the bottom of the case wherever makes sense for you. Typically this is done on the **bottom edge** of the foot and the bottom left and right corners. The pad placement should take care of any *skew* in your case.
14. Place your keycaps on the switches 🙌
15. Use VIA to configure your keymapping! 🎉 [Using VIA reference](using_via.md)
16. Experts: [customize your firmware](firmware_customization.md)

## Errata

- MX style switches require relatively tight tolerances for the switch plate. This includes 0.551 ± 0.002 dimensions for the cut-out and 0.060 ± 0.004 for the thickness of the plate. The acrylic that is sourced is marketed as 1.5mm (0.059") but often comes as thick as 0.067" this is 0.003" thicker than the specification and can make it extremely difficult for switches to clip in. Use a scredriver or other blunt object to put pressure on the switch-plate right at the clip location to get the switch to clip in. If applying direct pressure does not resolve the issue, you may need to use sandpaper to reduce the thickness of the plate at the clip in location (This is not normally necessary).

- The switch plate or PCB may warp in shipping or during assembly. This is acceptable in small amounts, but if there is two much pressure, it may add friction to the switches. To correct any major warping, support the edges of the switch plate or PCB with two books and put a small weight in the center. If you leave this overnight, the plate should plastically deform and hopefully become more flat.

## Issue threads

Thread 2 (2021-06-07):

PA9 and its 3-pin connector

GreenCapMan, 2021-06-07:
Hi there,

I come here from your youtube channel and I want to make PCB for single hand keyboard. I was trying to copy your design idea. I found that you had a connector with Vcc, ground, and PA9, of which the usage is not explained in your video. What is the purpose  of this connector? Is it for debug for the PCB when you received from the manufacturer?

BTW, very nice video and cute cats XD

Thanks a lot

camrbuss, 2021-10-12:
It could be used for anything, leds, another screen, or powering something else.

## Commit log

2020-11-29 V0 KiCad 5.99 PCB (#1)
    * pcb with peripherals but no switches
    * switches added
    * switches placed
    * fixed component positions
    * corrected OLED pads
    * Switch inputs linked to mcu
    * right switch traces
    * Routed PCB
    * V0 prelim
    * solder mask bridge minimum
    [grabert.kicad_sch]
2020-11-30 Initial switchplate CAD
    [grabert.FCStd]
2020-12-01 Switch plate features complete
    [grabert.FCStd]
2020-12-05 Acrylic Case Assembled
    [grabert.FCStd]
2020-12-05 pcb added to cad with feet
    [grabert.FCStd, grabert_pcb.FCStd]
2020-12-06 case adjustments
    [grabert.FCStd, grabert_pcb.FCStd, ssd1306oled128x32.FCStd]
2020-12-16 Initial proto laser cut
    [grabert.FCStd]
2021-04-06 pcb: added 100nF bypass caps
    [grabert.kicad_sch]
